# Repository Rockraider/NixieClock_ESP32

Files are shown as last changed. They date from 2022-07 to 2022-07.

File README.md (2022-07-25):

# NixieClock_ESP32
Nixie Clock with ESP32 for NTP time

## CAUTION - DANGER!
Do not touch the PCB if it is connected to a power source. Input voltage gets transformed to 170V DC!!

Always use with housing and keep away from children!

## Nixie Tubes:
IN-14 Nixie tubes are used with SN74141 drivers. Nixies need high voltage so NCH8200HV is used as DC-DC converter.

## Brain
The brain is a ESP32 (NodeMCU-32SLUA) which is stacked on bottom side for easy outside flashing.
It connects to wifi and synchronizes the time via NTP. You might have to edit the time zone.
Daylight Saving Time is recognized.

## Flashing
Flashing is simple on NodeMCU-32SLUA with onboard USB. Plug it in, open project with Arduino IDE. Enter your Wifi SSID and password and upload.
For your own safety do not flash while stacked to the PCB!

Note: The PCB onboard Micro-USB is only used for powering the device, flashing is not possible.

## Power Supply
5V Power supply is needed.

A common (phone) USB charger could be used to power the device. Connector is a Micro-USB. 

For battery powered see optional features.

## Housing
I designed a simple 3D-printable housing, where the PCB could be attached inside.

Get it on thingiverse: https://www.thingiverse.com/thing:5441650

## Optional features

### USB out
There is a optional USB-A output which is just a passthrough of the input. 

You could use it to power another device, if your supply is powerful enough.

### WS2812B
There are pads under the tube sockets to put on WS2812B LEDs for coloring the tubes. 

I didn't used them, cause the tubes had a nice blue flair itself. 
Feature is untested.

### Battery supply
If you want to power the device without the Micro-USB connector you could use the "H1" 2x1 header.
It's directly connected to Vcc and GND similar to the power connector.

### Additional IOs
Got your own idea to extend functionality? Do you want to use it as alarm clock and attach a bell or something fancy?
There is a 3x2 header "J1" which containes Vcc, GND and two IOs connected to NodeMcu Pins P32/33.

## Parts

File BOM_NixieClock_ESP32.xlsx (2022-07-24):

ID | Name | Designator | Footprint | Quantity | Manufacturer Part | Manufacturer | Supplier | Supplier Part | Comment
1 | 100nF | C1,C2,C3,C4,C5 | C0603 | 5 | CL10B104KO8NNNC | SAMSUNG | LCSC | C66501
2 | Header-Male-2.54_1x2 | H1 | HDR-TH_2P-P2.54-V | 1 | 826629-2 | TE Connectivity | LCSC | C86471
3 | Header-Male-2.54_2x3 | J1 | HDR-TH_6P-P2.54-V-R2-C3-S2.54 | 1 | Header-Male-2.54_2x3 | BOOMELE | LCSC | C65114
4 | WS2812B | LED1,LED2,LED3,LED4 | LED-5050_4P | 4 | WS2812B | Worldsemi | LCSC | C114585 | optional, untested
5 | NCH8200HV | M1 | NCH8200HV | 1 | NCH8200HV |  | ebay | NCH8200HV
6 | 10K | R1,R2,R3,R4 | R1206 | 4 | RC1206FR-0710KL | YAGEO | LCSC | C132649
7 | 470 | R5 | R0603 | 1 | RC0603JR-07470RL | YAGEO | LCSC | C114433 | optional, for WS2812B
8 | Nixie-IN-14 | U1,U3,U5,U7 | NIXIE IN-14 | 4 | Nixie-IN-14 |  | ebay
9 | SN74141 | U2,U4,U6,U8 | DIP16 | 4 |  |  | ebay
10 | Ai-Thinker_NodeMCU-32SLUA | U10 | AI-THINKER_NODEMCU-32SLUA | 1 | NodeMCU-32SLua | Ai-Thinker | LCSC | C111436
11 | USB-CON-MICRO-B-5S | USB1 | MICRO-USB-SMD_MICRO-5P5.9 | 1 | USB-CON-MICRO-B-5S | ValuePro | LCSC | C40954
12 | USB A/F90°(14.1) | USB2 | USB-A-TH_USB-M-1 | 1 | USB A/F90°(14.1) | ValuePro | LCSC | C2344 | optional, passthrough to load an additional device

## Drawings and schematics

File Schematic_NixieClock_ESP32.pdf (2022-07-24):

# GND⁵V

# GND⁵V

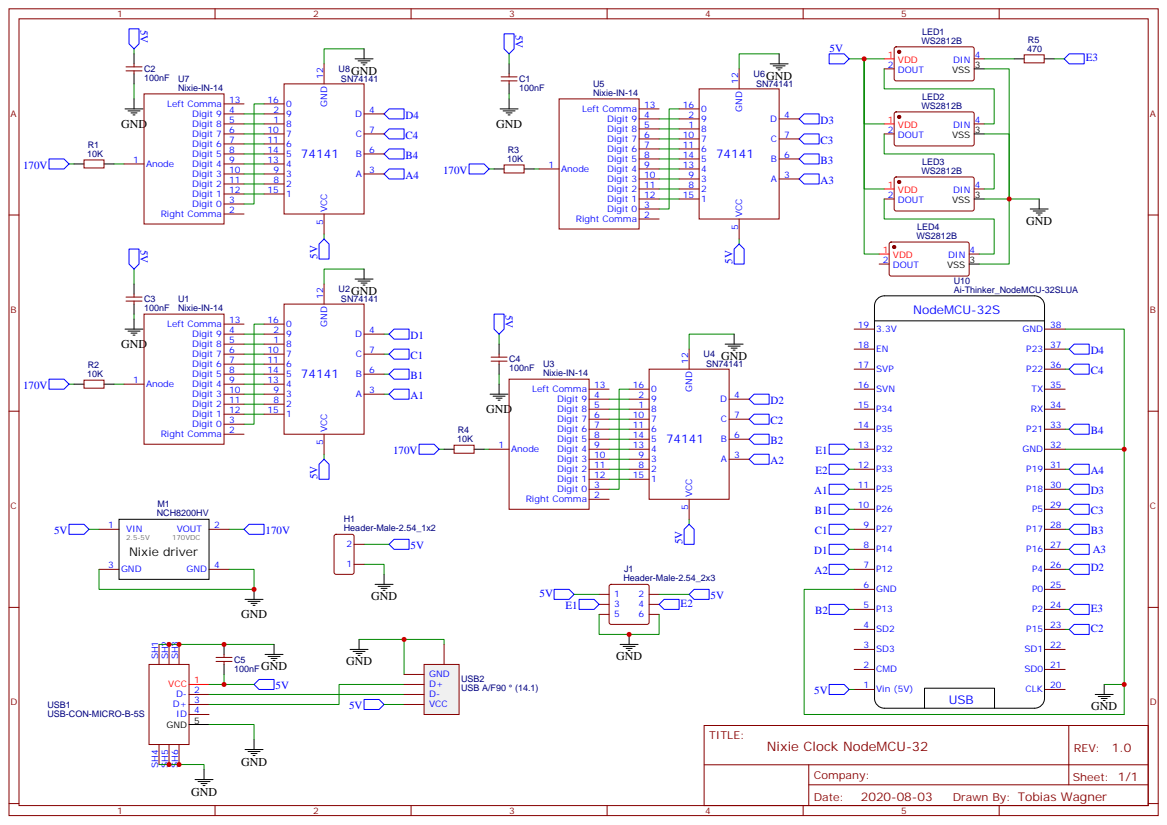
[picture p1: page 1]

Drawn By: Tobias Wagner

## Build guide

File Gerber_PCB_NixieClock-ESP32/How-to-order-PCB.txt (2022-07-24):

How to Order PCB

Please refer to:
https://docs.easyeda.com/en/PCB/Order-PCB

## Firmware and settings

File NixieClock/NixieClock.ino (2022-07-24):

/*
 * @title Nixie Clock ESP32
 * @version 0.1.0
 * @author: Tobias Wagner
 * @ide: Arduino 1.8.9
 * 
 * NTP time
 */

//#include <FastLED.h>
#include <Time.h>
#include <TimeLib.h>
#include <NTPClient.h>
#include <WiFi.h>
#include <Wire.h>

#define LED_PIN     2
#define NUM_LEDS    4
#define A1 25
#define B1 26
#define C1 27
#define D1 14
#define A2 12
#define B2 13
#define C2 15
#define D2 4
#define A3 16
#define B3 17
#define C3 5
#define D3 18
#define A4 19
#define B4 21
#define C4 22
#define D4 23
#define AUX_1 32
#define AUX_2 33

char A[4] = {A1, A2, A3, A4};
char B[4] = {B1, B2, B3, B4};
char C[4] = {C1, C2, C3, C4};
char D[4] = {D1, D2, D3, D4};

const char *ssid     = "YOUR_SSID";
const char *password = "YOUR_PW";

int zero;
int one;
int two;
int three;
int epochhour = 0;
int epochminute = 0;
int epochsec = 0;
unsigned long epoch = 1571270400;
unsigned long fetchedTime = 0;

int every_min = 0;

WiFiUDP udp;

NTPClient timeClient(udp, "europe.pool.ntp.org", 1*3600, 60000); //1* = GMT:+1

//CRGB leds[NUM_LEDS];
//CHSV colour( 0, 255, 180);


void setup(){
  pinMode(LED_PIN, OUTPUT);
  pinMode(A1, OUTPUT);
  pinMode(B1, OUTPUT);
  pinMode(C1, OUTPUT);
  pinMode(D1, OUTPUT);
  pinMode(A2, OUTPUT);
  pinMode(B2, OUTPUT);
  pinMode(C2, OUTPUT);
  pinMode(D2, OUTPUT);
  pinMode(A3, OUTPUT);
  pinMode(B3, OUTPUT);
  pinMode(C3, OUTPUT);
  pinMode(D3, OUTPUT);
  pinMode(A4, OUTPUT);
  pinMode(B4, OUTPUT);
  pinMode(C4, OUTPUT);
  pinMode(D4, OUTPUT);
  for (char i = 0; i < 4; i++) {
    digitalWrite(A[i], HIGH);
    digitalWrite(B[i], HIGH);
    digitalWrite(C[i], HIGH);
    digitalWrite(D[i], HIGH);
  }
  Serial.begin(115200);
  WiFi.begin(ssid, password);

  //FastLED.addLeds<WS2812, LED_PIN, GRB>(leds, NUM_LEDS);
  //FastLED.setBrightness(255);
  
  while (WiFi.status() != WL_CONNECTED) {
    delay(500);
    Serial.print(".");
  }
  Serial.println("connected");

  timeClient.begin();
}


boolean summertime_EU(int year, byte month, byte day, byte hour, byte tzHours)
// European Daylight Savings Time calculation by "jurs" for German Arduino Forum
// input parameters: "normal time" for year, month, day, hour and tzHours (0=UTC, 1=MEZ)
// return value: returns true during Daylight Saving Time, false otherwise
{
  if (month<3 || month>10) return false; // keine Sommerzeit in Jan, Feb, Nov, Dez
  if (month>3 && month<10) return true; // Sommerzeit in Apr, Mai, Jun, Jul, Aug, Sep
  if (month==3 && (hour + 24 * day)>=(1 + tzHours + 24*(31 - (5 * year /4 + 4) % 7)) || month==10 && (hour + 24 * day)<(1 + tzHours + 24*(31 - (5 * year /4 + 1) % 7)))
    return true;
  else
    return false;
}


void loop() {

  //get time 
  timeClient.update();
  epoch = timeClient.getEpochTime();
  if (summertime_EU(year(epoch), month(epoch), day(epoch), hour(epoch), 1) == true)
  {
    epoch += 3600;
  }
  epochhour = (epoch  % 86400L) / 3600;
  epochminute =(epoch % 3600) / 60;
  epochsec =(epoch % 60);

  zero = (epochhour / 10) % 10;
  one = epochhour % 10;
  two =  (epochminute / 10) % 10;
  three = epochminute % 10;

  
  if (every_min != epochminute)
  {
    writenumber(0, zero);
    writenumber(1, one);
    writenumber(2, two);
    writenumber(3, three);
    Serial.print(zero);
    Serial.print(one);
    Serial.print(":");
    Serial.print(two);
    Serial.println(three);
    every_min = epochminute;
  }
  
  //FastLED.show();
  
}

void writenumber(int a, int b) {
  switch (b) {
    case 0:
      digitalWrite(A[a], LOW);
      digitalWrite(B[a], LOW);
      digitalWrite(C[a], LOW);
      digitalWrite(D[a], LOW);
      break;
    case 1:
      digitalWrite(A[a], HIGH);
      digitalWrite(B[a], LOW);
      digitalWrite(C[a], LOW);
      digitalWrite(D[a], LOW);
      break;
    case 2:
      digitalWrite(A[a], LOW);
      digitalWrite(B[a], HIGH);
      digitalWrite(C[a], LOW);
      digitalWrite(D[a], LOW);
      break;
    case 3:
      digitalWrite(A[a], HIGH);
      digitalWrite(B[a], HIGH);
      digitalWrite(C[a], LOW);
      digitalWrite(D[a], LOW);
      break;
    case 4:
      digitalWrite(A[a], LOW);
      digitalWrite(B[a], LOW);
      digitalWrite(C[a], HIGH);
      digitalWrite(D[a], LOW);
      break;
    case 5:
      digitalWrite(A[a], HIGH);
      digitalWrite(B[a], LOW);
      digitalWrite(C[a], HIGH);
      digitalWrite(D[a], LOW);
      break;
    case 6:
      digitalWrite(A[a], LOW);
      digitalWrite(B[a], HIGH);
      digitalWrite(C[a], HIGH);
      digitalWrite(D[a], LOW);
      break;
    case 7:
      digitalWrite(A[a], HIGH);
      digitalWrite(B[a], HIGH);
      digitalWrite(C[a], HIGH);
      digitalWrite(D[a], LOW);
      break;
    case 8:
      digitalWrite(A[a], LOW);
      digitalWrite(B[a], LOW);
      digitalWrite(C[a], LOW);
      digitalWrite(D[a], HIGH);
      break;
    case 9:
      digitalWrite(A[a], HIGH);
      digitalWrite(B[a], LOW);
      digitalWrite(C[a], LOW);
      digitalWrite(D[a], HIGH);
      break;
  }
}

void off(int a) {
  digitalWrite(A[a], HIGH);
  digitalWrite(B[a], HIGH);
  digitalWrite(C[a], HIGH);
  digitalWrite(D[a], HIGH);
}
